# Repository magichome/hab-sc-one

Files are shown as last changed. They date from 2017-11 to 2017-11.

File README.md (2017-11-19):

## SCHab One
Definition: SCHab - _Shipping Container Habitat_

### Description
This is an effort to design a self-contained habitat based on a standard 40' HC Shipping Container.  It's more than just a drawing.  I plan to research, document, and design each subsystem that goes into building such a habitat: electrical, plumbing, hvac, etc.  Then I plan to build one.

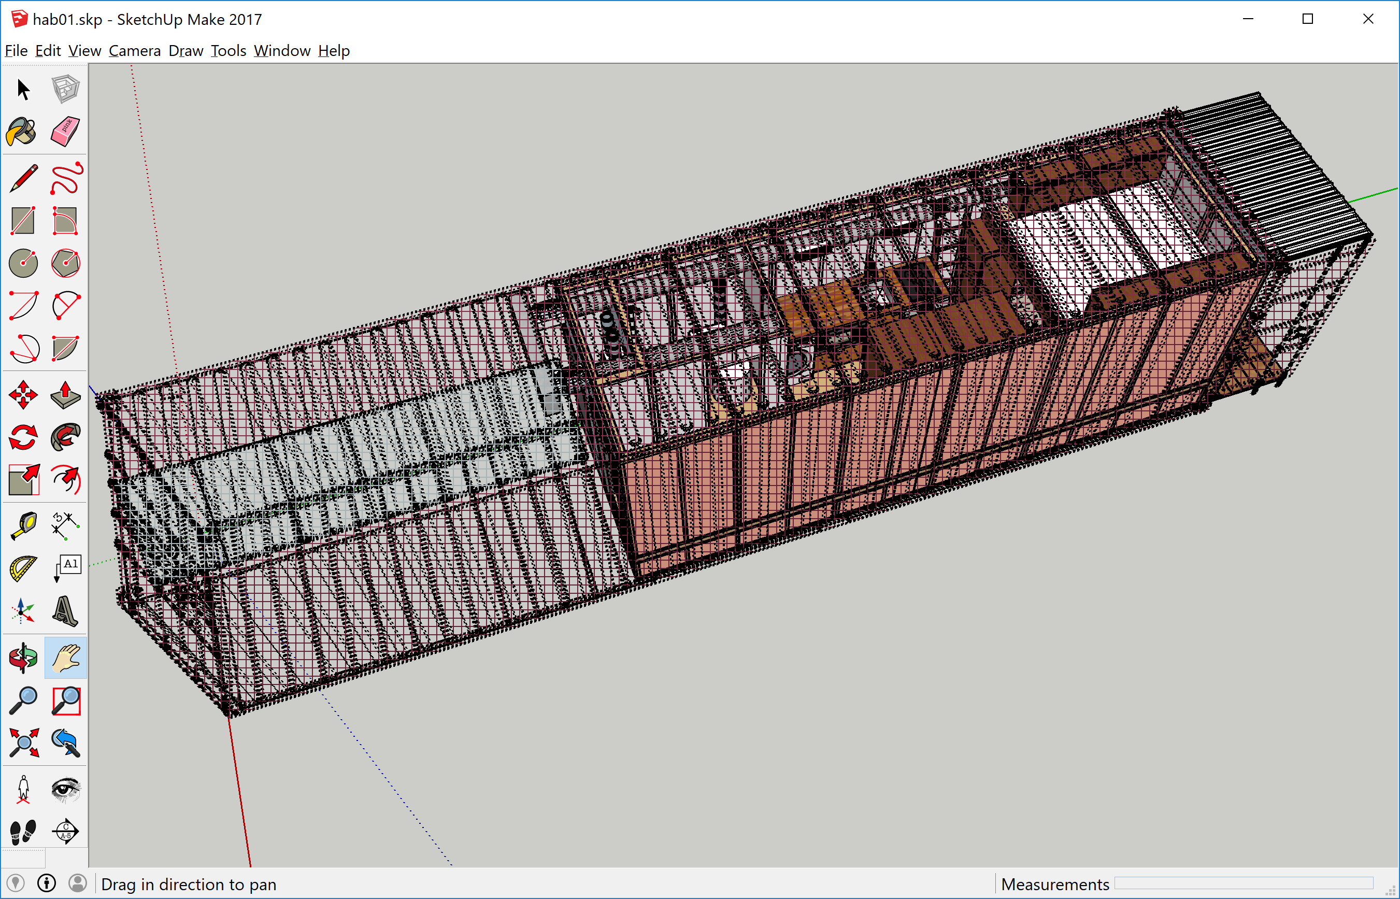
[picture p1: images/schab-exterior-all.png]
Exterior View


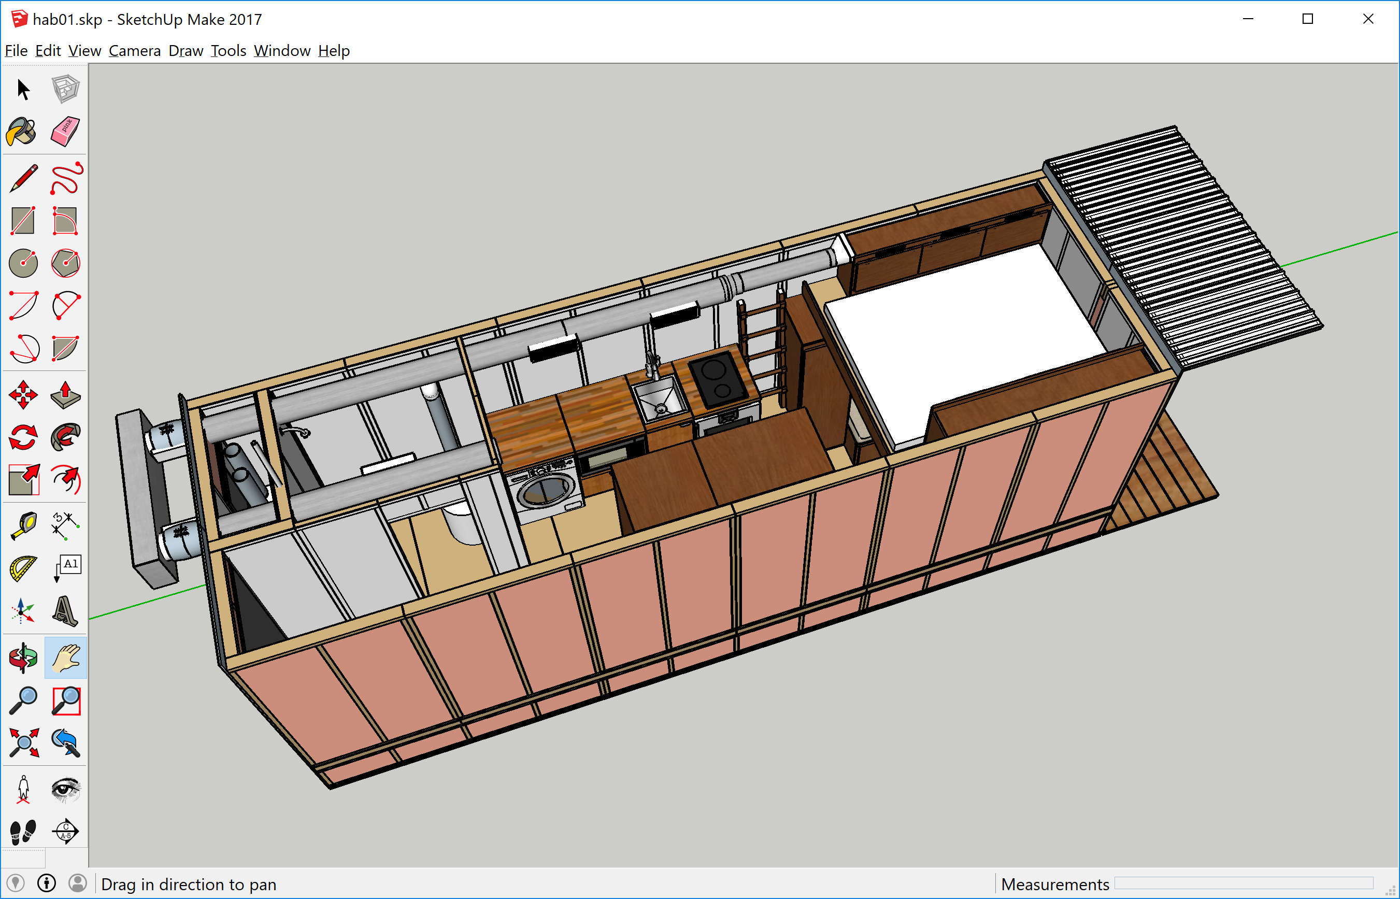
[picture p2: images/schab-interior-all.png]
Interior View


### Background
In order to explain why we're doing this, let me share a little background.  Currently we live in a small RV*.  We travel around the country as required by work or inclination.  While we've been doing this for about 4 years, I know we won't be doing it forever.  I can see a point when we'll want to spend time in a single location for part of the year.  Maybe at first a mixture of RV living and settled living.  Later probably more toward settled living.

**But why use a shipping container?**

A few reasons.  First, when we decided to live in an RV, mobility was the main requirement.  But we also wanted to downsize - minimal lifestyle, minimal impact, minimal cost.  A shipping container has more than enough room for us.  In fact it will be a step up from our current ride.

Second, we don't know where we'll buy land to set this up - we'll figure that out as we continue our current nomadic living.  We do have a place where we can start construction on the habitat and work on it for a few months out of the year.  So we can start building it now, purchase land later, and relocate it.

Third, even though we plan to buy land for SCHab, its unlikely we'll want keep it in one place indefinitely.  Maybe a location that appeals to us a few years from now won't work us 10 years from now.  The self contained shipping container habitat that we're planning will be relocatable. If we get tired of one place, we can have it moved to another.

**Why not a single-wide or 5th wheel trailer?**

Either of these could work but they are generally not self container.  They need water, sewer and electrical hookup.  The kind of land we're considering is generally off-grid and far from public utilities.  Electric could be brought in but that drives up the cost.  Adding a well and septic system also drives up the cost.  Minimal cost is one of our design goals.

Security is also a consideration.  Since we may only occupy our SCHab a few months out of the year, we want it to be as secure as possible while we're gone.  While nothing will keep out a determined bugler with the proper tools, a shipping container will be harder to break into than any trailer.  A shipping container will also stand up to harsh weather better.

And besides, this planning and construction is fun!

### Features
Since this is a work-in-progress the features are evolving.  Since we're use to living in our RV, some of these choices were informed by things that are working for us now.  Here's what I have so far:
* Completely contained in a 40' HC double-door shipping container.
* Single sleep area with queen size mattress
* Porch area for covered outdoor seating
* 7' x 15' garage area for a vehicle or outdoor toys
* Solar or wind electric with battery storage and AC inverter
* Single unit washer / dryer
* Marine refrigerator / freezer (12vdc)
* Oven / Stove / Microwave
* On-demand water heater (propane)
* Radiant heat
* Waterless toilet
* Storage tank for rainwater harvesting
* Provisions for a second story for those who need more space

### Getting Started
Drawing were made using [SketchUp](https://www.sketchup.com/).  The "free for non-commerical use" version, called SketchUp Make, can be downloaded at https://www.sketchup.com/download.  If you want to look at the drawings, you'll need to download and install SketchUp.

You'll want a local copy of this repository with all of the design files.  If you have GIT, you can clone the repository in the usual way.  If you have no idea what that means, you can download a zip archive by selecting the "Clone or Download" button above.

Some of the analysis is done using Microsoft Excel worksheets.  If you don't have Excel you can use the free office suite [Libre Office](https://www.libreoffice.org/).

### Project Resources

| Link | Purpose |
| --- | --- |
| [Research](Research/Research.md) | Information captured from research into various aspects of the project. |
| [Requirements](Requirements/Requirements.md) | Capture requirements for SCHab and its various subsystems. |
| [Design](SketchUp/Design.md) | 3D drawings |
| [Construction](Construction/Construction.md) | Information about construction considerations. |
| [Control](Control/Control.md) | Monitoring and control system. |
| [Trello Board](https://trello.com/b/0bdXyXfJ) | Here you can check on tasks I've identified and my status on those tasks. |

### Disclaimer

I am not an architect or engineer.  I didn't even stay at a Holiday Inn Express last night.  My background is science and IT.  While I'm aware of many building codes, I won't claim that any of what I have here is proper or up to code.  Frankly since this is "temporary housing", I'm not even sure what building codes apply.  Since my plan is to locate our SCHab in unincorporated areas, I'm not too concerned about it.  Obviously if you plan to build one yourself you'll want to understand the CC&R of the land you purchase and the building codes of the community.

Also, products we mention may link to Amazon.  As such, Amazon requires that we tell you the following:

"We are a participant in the Amazon Services LLC Associates Program, an affiliate advertising program designed to provide a means for us to earn fees by linking to Amazon.com and affiliated sites.”

--

\* You can read more about the RV on our blog (https://www.b190exp.com/) and follow us on [Instagram](https://www.instagram.com/b190exp/)

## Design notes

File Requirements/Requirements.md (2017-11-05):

## SCHab One : Requirements

Its generally a good idea to have in mind what you want, your requirements, before you go about designing and building it.  Here's what I have in mind for the requirements of SCHab One.

| General Requirements |
| ----- | ----- |
| No. | GEN01 |
| Title | SCHab shall be completely transportable in a single 40' HC Shipping Container. |
| Description | While some components of SCHab may be placed outside the container while in use, everything must be attached or contained within the container so it can be shipped as a single unit. |
| | |
| No. | GEN02 |
| Title | Other than service entries, SCHab shall not have penetrations in the shipping container skin. |
| Description | Entry will be at either end with the shipping container doors open.  Other than vents, water, sewer and electrical connections, there will be no other openings in the container (e.g. no doors or windows on the sides.) |
| | |
| No. | GEN03 |
| Title | SCHab shall require minimal site preparation. |
| Description | Other that the need to be level and room to open the doors, SChab shouldn't have any onerous site requirements. |
| | |
| No. | GEN04 |
| Title | SCHab shall provide suffcient sleeping space for 2 adults. |
| Description | In other words, a queen size bed. YMMV |

| Electrical Requirements |
| ----- | ----- |
| No. | ELEC01 |
| Title | Combined electrical generation and storage capacity shall meet 120% of expected average load over the course of habitation period. |
| Description | Some excess capacity is needed to support future growth.  At the same time it isn't necessary to provide capacity for those periods where the habitat is expected to be empty. |
| | |
| No. | ELEC02 |
| Title | Combined electrical generation and storage capacity shall meet 120% of the minimal sustaining load over the course of the non-habitation period. |
| Description | When we're not living in our SCHab, it will still have some electrical load requirements.  E.g. security and monitoring system, freeze protection, etc.
| | |

| Plumbing Requirements |
| ----- | ----- |
| No. | PLUM01 |
| Title | Water collection plus reserve supply shall meet 110% of the expected average usage during the habitation period. |
| Description | Compared to electric, water is a little easier to conserve so its requirement is a little lower. |
| | |
| No. | PLUM02 |
| Title | Black water and gray water shall be handled separately. |
| Description | While not all jurisdictions differentiate between black water and gray water, they can be handled differently.  For example, gray water can be recycled for irrigation.  I make sense to keep them separate. |

| Heating Requirements |
| ----- | ----- |
| No. | HEAT01 |
| Title | Heating generation capacity shall be sufficient to maintain a minimum of 65F during the coldest average conditions during the habitation period. |
| Description | This is complicated because it depends largely on the heat leakage of SCHab.  We'll take a stab at it. |
| | |
| No. | HEAT02 |
| Title | SCHab shall maintain HEAT01 for a period of 60 days without manual intervention. |
| Description | This deals with the size of the propane tanks.  I don't want to be having them refilled more frequently than this. |

| Ventilation Requirements |
| ----- | ----- |
| No. | VENT01 |
| Title | Ventilation shall be sufficient to keep indoor temperature within 5F of outside ambient temperature. |
| Description | I'm just pulling this one out of my rear.  I know that it is hard to keep a big, closed container cool with the sun beating down on it. Basically it needs enough ventilation to not become a sweat box on mild days. |

| Construction Requirements |
| ----- | ----- |
| | |

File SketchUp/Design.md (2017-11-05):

## SCHab One : Design

### Tools

Drawing were made using [SketchUp](https://www.sketchup.com/).  The "free for non-commerical use" version, called SketchUp Make, can be downloaded at https://www.sketchup.com/download.

### Schematics

These are found in the 'Schematics' directory.

### 3D Drawnings

The main SCHab 3d drawing is the file _hab01.skb_.  It is built up of components that can be found in the various SketchUp subdirectories.  These components can be opened and edited in SketupUp individually.  Note, however, that changes are not automatically reflected in the overall hab01.skb drawing.  You would need to select the component in hab01.skb and "reload" it from the edited component file.

I found the [shipping container model](https://3dwarehouse.sketchup.com/model/ub2c368e2-d333-4a4c-81ff-acfce363f53e/Open-Top-40ft-High-Cube-Container-w2-Doors) in the SketchUp 3D Warehouse.  It was created by OrganicZero so they deserve credit for it.

### HVAC

I don't plan for air conditioning in the current design.  If you need A/C, it may be possible to add an evaporator coil to the ventilation input duct and add a return air duct somewhere.  One could certainly add a split unit.  Instead I have a couple high volume blowers that will circulate outside air.  That along with  natural ventilation through screen doors should help keep the temperature down.

For heating, the space is small enough it could be heated with a pellet stove.  So in some sense radiant heat (my choice) is overkill.  Having lived with radiant heat in the past, I like it.  So here it is.

On a personal note, before I started living in an RV I had a fairly narrow comfort range for home temperature.  About 71F in the winter and 69F in the summer.  Now I find that I can function just fine with temperatures anywhere between 60F and 90F inside.  You just get use to it.  So I'm not inclined to design an HVAC system according to my old sensibilities.  YMMV.

#### Radiant Heat

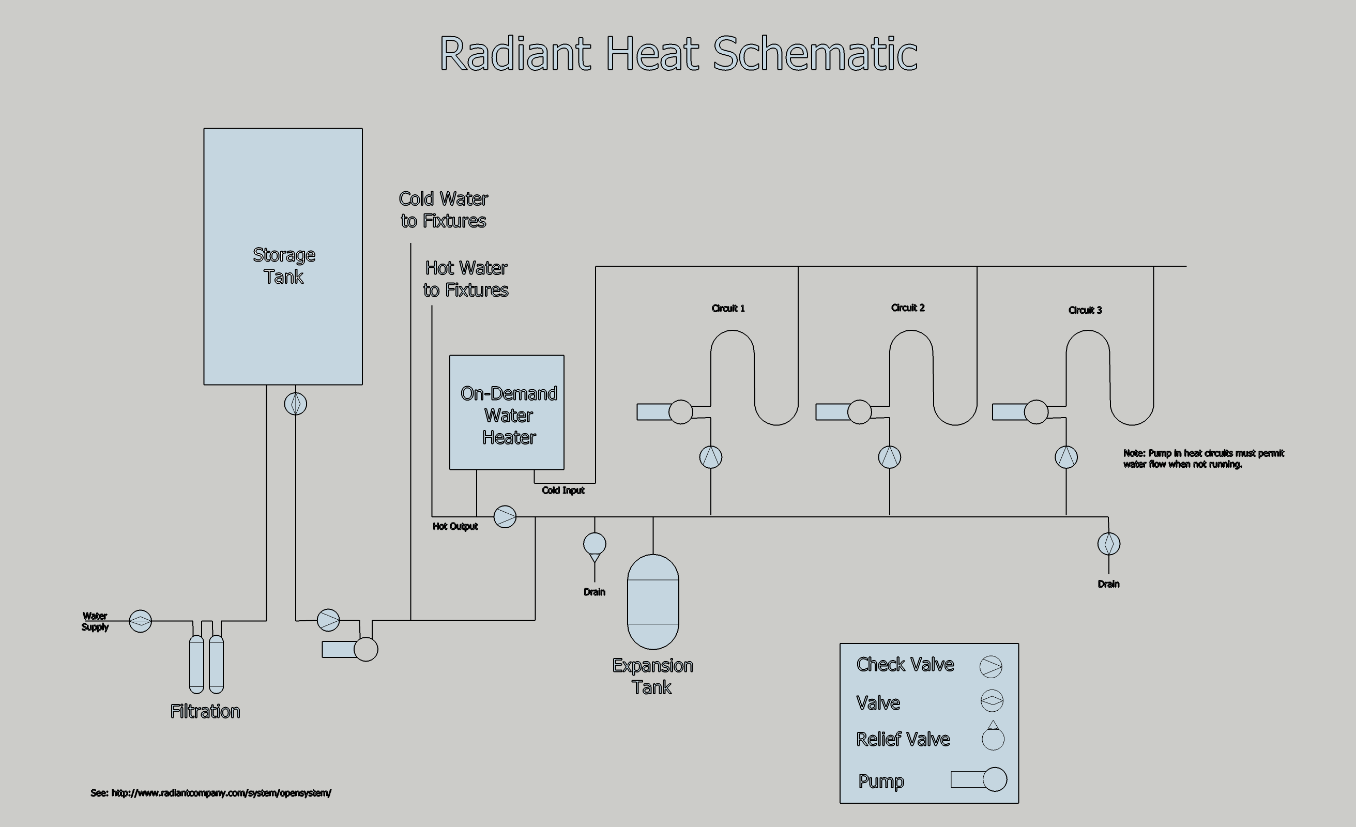
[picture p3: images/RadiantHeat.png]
Schematic


This is an open loop system.  That means the water that heats the floor is the same water that comes out of the faucet.  With a system like this you need to make sure the water is circulated throughout the system even when heat isn't used.  You don't want the water to stagnate.  That's why you see the (strange) connection between the cold water input and the radiant heat circuit.  Basically the on-demand water heater's cold water input is through the radiant heat system.  The folks at  [www.radiantcompany.com](http://www.radiantcompany.com/system/opensystem/) explains how this works so I won't repeat it here.

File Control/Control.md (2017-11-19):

## SCHab One : Control

Given my background in IT, you shouldn't be surprised that I intend to trick out SCHab with some impressive monitoring and control gizmos.

### Monitoring
* Indoor air temperature
* Outdoor air temperature
* Battery voltage
* Solar / Wind current input
* Usage current
* Water temperature input to radiant heat circuits
* Water temperature return from each circuit
* Water pressure
* Water storage tank level
* Propane tank levels

### Control
* Radiant heat pumps
* Ventilation fan speed
* Lights

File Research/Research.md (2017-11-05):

## SCHab One : Research

Several subsystems of SCHab are complex topics in their own right.  Here I look for resources that have already done some of the heavy lifting.  Research topics include:

* [Rainwater Harvesting](#rainwaterharvesting)
* [Gray Water Disposal](#greywaterdisposal)
* [Gray Water Recycling](#greywaterrecycling)
* [Solar Power Generation](#solarpower)
* [Wind Power Generation](#windpower)
* [Radiant Heat](#radiantheat)
* [Purchasing Shipping Containers](#scpurchase)
* [Transporting Shipping Containers](#sctransport)

### Rainwater Harvesting

First, I don't want to have a well drilled.  Depending on location this can be quite expensive.  A well also increases the electrical requirements.  I know that statistics show the average person takes some 25 - 50gal per day.  I also know, living in the RV, that I can made do with much less.  I don't have big water wasters like lawn watering, a flush toilet, or long showers.  So rainwater harvesting seems like a viable solution.

From my research so far, harvesting off a shipping container is problematic.  First, its flat.  The rainwater will run off all over the place.  Even if we could catch it, 40' x 8' isn't much of a collection area.  There are few places in the country where 320 sq ft of collection area will give you enough water.

There is also the question of storage.  I have designed in a 275 gal bladder tank in the crawl space.  That will help get through some dry months but it isn't a huge amount.

Generally rainwater harvesting is broken down into the following categories:

* Collection
* Storage
* Filtration
* Treatment

Collection is mainly focused on the surface area required to collect the amount of water you'll need given the average rainfall in your area of choice.  You'll get roughly 0.62 gal per sq ft per inch of rain.  My [RainHarvestingProjections.xlsx](Research\RainwaterHarvesting\RainHarvestingProjections.xlsx) spreadsheet shows some calculations for a couple locations.

Storage is needed to carry you through times when there is no rain.  So while collection area can be based on average annual rainfall, you'll need to look at monthly rainfall averages to determine storage requirements.  Let's say, for example, that a location gets 50in of rain per year.  You can design the collector to capture enough of that 50in to satisfy your needs.  But say that those 50in only come over a couple months in the spring.  Then you'll need a large storage capacity to keep you in water for the other 10 months.  On the other hand, if those 50in are spread evenly over the year, you'll need less storage.  Maybe only enough to carry you for a week or two.  The above spreadsheet takes that into consideration.

Filtration removes particulates from the water.  It is a multi-stage process that starts with screens at the gutters, a 'first flush' mechanism, particulates settling out in the storage tank, then two or three filters.

Treatment kills microorganisms that may be in the water.  I'm leaning toward a UV system since that seems easiest to install and maintain.

Most rainwater harvesting designs do things in this order:

collection -> storage -> filtration -> treatment

I've decided though that I don't want unfiltered or untreated water in my storage tank.  I don't want particulates settling out in my storage tank because I don't want to worry about periodically cleaning it out.  Instead I'm thinking of the following:

collection -> catch basin -> filtration -> treatment -> storage

The catch basin would be outside and sized to collect the water from an average rainfall.  A pump would move the water from there, through the filtration/treatment system and into storage. I haven't research this much so I don't have answers to these questions:

* How fast can I pump water through the filtration/treatment system?  If we have a deluge, can I pump it fast enough to keep the catch basin from overflowing?
* How do I keep all of this from freezing in the winter?
* How do I harvest snowfall if that becomes a consideration?

### Gray Water Disposal

Let's speak frankly.  Gray water is the waste water you generate than doesn't have poop.  Black water is waste water that does have poop.  Since I'm planning to use a waterless toilet, all of the waste water for SCHab will be gray water.  

Note: Some jurisdictions treat gray water the same as black water.  If you're in one of those areas, you'll need a septic system anyway.

You could just run the gray water onto the ground.  In the interest of full disclosure, the SCHab gray water will have pee.  (Urine is quite sterile but not everyone knows that.)  Having urine smell around your SCHab is probably not a good idea.  Right now I'm thinking of a [french drain](https://en.wikipedia.org/wiki/French_drain) located some distance from the SCHab.  That may change if it looks like gray water recycling (e.g. garden irrigation) would be a good idea for me.

Note: You don't want to store gray water unless you plan to later dispose of it as black water.  The microbes in gray water will eventually turn it septic.

### Gray Water Recycling

If you're in a really arid region you may want to keep every drop of water you can.  Is it possible to pump your gray water back into your rainwater harvesting system and not make everyone sick?  I'm sure it's possible (they recycle water on the ISS) but it may not be practical.  

Irrigating a garden is an easy recycling plan. Just plumb the gray water drain pipe to irrigation pipes.  Maybe a diverter valve to a french drain to control the amount of water to the garden.

### Solar Power Generation

This one is easy for me.  We use solar power in our RV.  Renogy solar panels, Vmaxtank AGM batteries, and MPPT charge controller are my choice.  I am going to try Renogy's polycrystalline panels this time even though I have monocrystalline panels on the RV.  Polys are less expensive but less efficient than monos.  Poly panels need to be larger to get the same power output.  On my RV, with limited roof space, smaller panels are a good thing.  On SCHab it's less important so I'd rather have the lower cost.  The main question here is how many panels and batteries do I need for the electrical load.

### Wind Power Generation

I've not used wind power but considering it due to my acute familiarity with the limitations of solar.  If you're in an area with long periods of cloudy skies you may need to dramatically increase the number of solar panels and batteries necessary to keep the lights on.  That isn't cheap.  Depending on location, it may make sense to supplement solar power generation with wind.  More research to come.

### Radiant Heat

Coming...

### Purchasing Shipping Containers

SCHab will use a 40' HC DD shipping container. 40' because that's its length.  HC mean 'high cube' with means 9'6" tall instead of the usual 8'6" tall.  DD mean 'double-door', a door at both ends.  I won't go into all of the ins and outs of shipping containers, e.g. new vs one-trip vs used.  A [simple Internet search](https://duckduckgo.com/?q=shipping+or+conex+containers) will take care of that (search for 'conex' as well as 'shipping container').  I do believe that the double-door variant is harder to find.  Also, you'll want to buy local to cut down on transportation costs.  I'll do more here when I get closer to buying a container.

### Transporting Shipping Containers

Coming...

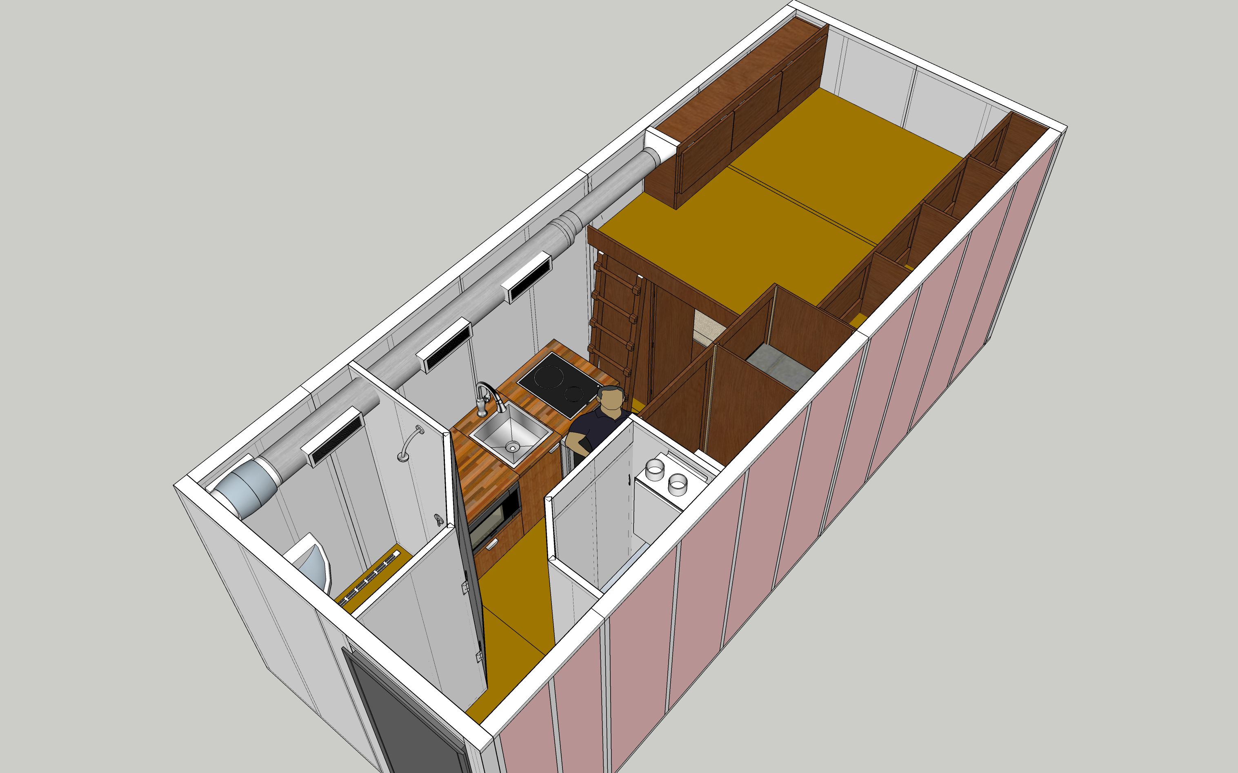
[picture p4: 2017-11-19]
images/hab-20-02.interior-allpng.png

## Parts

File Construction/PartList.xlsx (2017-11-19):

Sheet: Summary
Cost Summary
Appliances | $4705.00
Electrical | $3240.00
Solar | $1188.00
Wind | $0.00
Plumbing | $2580.00
HVAC | $360.00
Construction | $6343.11
Total | $18416.11

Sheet: Appliances
Item | Make | Model | Watts | Price Est | Supplier | Notes
Microwave |  |  |  |  |  | 22"
Range Hood |  |  |  |  |  | 22"
Oven / Stove |  |  |  |  |  | 22"
Washer / Dryer | LG | WM3488HW (http://www.lg.com/us/washer-dryer-combos/lg-WM3488HW-front-load-washer) | 1200 | $1415.00 | amazon.com (https://www.amazon.com/gp/product/B01H7HYF86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)
Waterless Toilet | Separett | Villa 9210 (https://separett-usa.com/index.php/waterless-urine-diverting-toilet.html) | 2.5 | $1190.00 | separett-usa-orders.com (https://www.separett-usa-orders.com/collections/waterless-toilets/products/villa-9210-dc)
LED TV | Vizio | D55-D2 | 40 | $580.00 | amazon.com (https://www.amazon.com/VIZIO-D55-D2-Class-Array-Smart/dp/B019PZD68I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) | Just an example to get idea of power requirements.
Refrigerator | Vitrifrigo | DP2600IBD4-F (http://www.vitrifrigo.com/us/us/dp2600ibd4-f-internal-cooling-unit) | 65 | $1520.00 | marinewarehouse.com (http://www.marinewarehouse.net/Vitrifrigo.html)
Total |  |  |  | $4705.00

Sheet: Electrical
Item | Make | Model | Watts | Qty | Price Est | Total | Supplier | Notes
Storage Battery | Vmaxtanks | SLR125 |  | 8 | $280.00 | $2240.00 | amazon.com (https://www.amazon.com/gp/product/B00ACNO2AO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)
Battery Monitor | Victron Energy |  |  | 1
Inverter | Sun Gold Power | 3000W |  | 1 | $640.00 | $640.00 | amazon.com (https://www.amazon.com/SUNGOLDPOWER-Inverter-Frequency-Converter-Priority/dp/B00QSWCZC0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)
DC Breaker Panel | Blue Sea Systems | Traditional 8-position |  | 1 | $190.00 | $190.00 | amazon.com (https://www.amazon.com/Traditional-Metal-DC-Panel-Positions/dp/B000K2MAYW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)
AC Breaker Panel | Blue Sea Systems | Traditional 6-position |  | 1 | $170.00 | $170.00 | amazon.com (https://www.amazon.com/Traditional-Metal-Panel-Main-Positions/dp/B0000AXNUY?s=sporting-goods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)
Lighting
Accent Lighting |  |  |  |  |  |  |  | Strip LED
Kitchen Ceiling Light
Kitchen Task Light
Bathroom Ceiling Light
Living Area Lighting
Bed Area Lighting
Utility Room Lighting
Crawl Space Lighting
Exterior Lighting
Total |  |  |  |  |  | $3240.00

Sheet: Solar
Item | Make | Model | Watts | Qty | Price Est | Total | Supplier
Solar Panel | Renogy | 100W Polycrystalline |  | 6 | $118.00 | $708.00 | amazon.com (https://www.amazon.com/Renogy-Polycrystalline-Photovoltaic-Solar-Module/dp/B00DCCOSV0?dpID=51PP4atr35L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)
Charge Controller | Renogy | 60A MPPT |  | 1 | $480.00 | $480.00 | amazon.com (https://www.amazon.com/dp/B01DCU4M0S?linkId=4fe2e1bcd93676475c9587820d5addf8)
Total |  |  |  |  |  | $1188.00

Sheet: Wind
Item | Description | Qty | Price Est | Total | Supplier | Notes
Total |  |  |  | $0.00

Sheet: Plumbing
Item | Make | Model | Watts | Qty | Price Est | Total | Supplier | Notes
Water Heater | Takagi | T-H3M (http://www.takagi.com/products/tankless-water-heaters/t-h3m-dv-p) | 54 | 1 | $790.00 | $790.00 | tanklessonline.com (http://www.tanklessonline.com/takagi-high-efficiency-tankless-water-heater-t-h3m-dv-p-indoor-propane.html) | On-demand. For both hot water and radiant heat.
Water Pump | Flojet | 2840-100 | 120 | 1 | $600.00 | $600.00 | pumpvendor.com
Holding Tank | Fol-Da-Tank | PW-275 (http://www.fol-da-tank.com/page/Collapsible%20Tanks%20for%20Water%20Shuttle%20and%20Storage.aspx?nt=138) | n/a | 1 | $760.00 | $760.00 | amazon.com (https://www.amazon.com/Fol-Tank-PW-275-SB-Pillow-Portable/dp/B01N6XZ4LE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) | Flexible tank so it can be removed from crawl space for cleaning or repair.
Bath Sink |  |  |  |  |  | $0.00
Bath Faucet |  |  |  |  |  | $0.00
Shower System | Perfetto | SP0057 | n/a | 1 | $230.00 | $230.00 | amazon.com (https://www.amazon.com/dp/B01HSFLYD6?linkId=c85b8255f12e06013fa0d67b8d8dbdac)
Shower Drain | DreamDrain | 48" Stainless | n/a | 1 | $100.00 | $100.00 | amazon.com (https://www.amazon.com/DreamDrain-Brushed-Stainless-Linear-Squares/dp/B013VR8I3Y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)
Kitchen Sink | Perfetto | 15" x 20" x 9" | n/a | 1 | $100.00 | $100.00 | amazon.com (https://www.amazon.com/Perfetto-Kitchen-Bath-Stainless-Undermount/dp/B073DF9QFR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)
Total |  |  |  |  |  | $2580.00

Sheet: HVAC
Item | Make | Model | Watts | Qty | Price Est | Total | Supplier | Notes
Ventillation Blower | Vortex | S-800 (http://vortexpowerfans.com/s800) | 232 | 2 | $180.00 | $360.00 | amazon.com (https://www.amazon.com/Vortex-711-CFM-S-Line-S-800/dp/B00EISCUQM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)
Circulation Pump |  |  |  | 3 |  |  |  | For radiant heat.
Pellet Stove |  |  |  |  |  |  |  | Optional, for cold climates.
Heat Exchanger |  |  |  |  |  |  |  | Could fit into ventilation duct. Optional, for cold climates.
Bath Exhaust
Inlet duct
Duct 8"
Duct 6"
Reducer 8" - 6"
Adapter 6" - rect
Duct Side Vent |  |  |  | 3
Duct End Vent
Cabinet Vent |  |  |  | 3
Total |  |  |  |  |  | $360.00

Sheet: Construction
Item | Description | Qty | Price Est | Total | Supplier | Notes
Shipping Container | 40ft HC DD | 1 | $4000.00 | $4000.00 |  | Estimate. Double-door harder to find.
Delivery Cost
Dimensional Lumber | 2" x 4" x 8' | 94 | $3.29 | $309.26
Dimensional Lumber | 2" x 2" x 8' | 15 | $1.78 | $26.70
OSB | 7/16" x 4' x 8' | 13 | $18.65 | $242.45
Insulation - Bat | 24" x 4" x 48" | 88 | $745.00 (https://www.homedepot.com/p/Owens-Corning-R30-Insulation-Unfaced-Batts-24-in-x-48-in-8-Bags-BU70/202756617) | $745.00 |  | Bundle price for 80.
Insulation - Panel | 1.5" x 4' x 8' | 6 | $24.00 (https://www.homedepot.com/p/Owens-Corning-Foamular-150-1-1-2-in-x-4-ft-x-8-ft-R-7-5-Scored-Squared-Edge-Insulation-Sheathing-88WD/202085958) | $144.00
Plastic Panel | 1/16" x 4' x 8' | 15 | $19.98 (https://www.homedepot.com/p/1-16-in-x-4-ft-x-8-ft-Plastic-Panel-63003/202090190) | $299.70
Gypsum Firebreak | 5/8" x 4' x 10'
Entry Door |  | 2 | $288.00 (https://www.homedepot.com/p/L-I-F-Industries-36-in-x-80-in-Gray-Right-Hand-Fire-Steel-Prehung-Commercial-Door-3RK/202080890) | $576.00
Utility Door
Bathroom Door
Total |  |  |  | $6343.11

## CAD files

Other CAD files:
SketchUp/Bath/LinearDrain.skp
SketchUp/Bath/shower_base_kohler9396.skp
SketchUp/Bath/sink-bathroom-2011-71-sk.skp
SketchUp/Bath/sink-corner.skp
SketchUp/Bath/toilet-waterless-separett.skp
SketchUp/Cabinets/CABINET+HANDLE+02.skp
SketchUp/Cabinets/Finial+Hinge.skp
SketchUp/Cabinets/cabinet-livingroom.skp
SketchUp/Cabinets/cabinet-wardrobe.skp
SketchUp/Cabinets/louvered+vents.skp
SketchUp/Cabinets/upper-vent-22in.skp
SketchUp/Components/32_+Shower+Stall.skp
SketchUp/Components/Base Panel.skp
SketchUp/Components/CrawlSpace-End.skp
SketchUp/Components/CrawlSpace-Side.skp
SketchUp/Components/Door-Steel-24in.skp
SketchUp/Components/Door-Steel-30in.skp
SketchUp/Components/DrawerSlides.skp
SketchUp/Components/Hinge+-+4.skp
SketchUp/Components/Insulation-CrawlSpace-Side.skp
SketchUp/Components/Insulation-FloorCeiling.skp
SketchUp/Components/Ladder-Bed-5ft.skp
SketchUp/Components/Lumber2x2.skp
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

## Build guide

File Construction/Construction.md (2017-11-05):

## SCHab One : Construction

### Tools

General carpentry tools should be sufficient for most of the construction.  Table saw, circular saw, nail gun, glue gun, etc.  Since the shipping container is steel, we'll also need some metal working tools.  Specifically we'll need to cut openings for vents on the roof and service entry on the side.  I plan to fabricate an elevated steel box for the vents and a recessed steel box for the service entry.  So you'll need an angle grinder with cutting wheels and a welder to weld the boxes to the shipping container.

### Construction Considerations

First, since SCHab is designed to be relocatable, we'll have to consider how transporting it can impact the structure.  Sliding on and off trailers, as well as bouncing along roads, is not something encountered by typical residential construction.  

Second, the steel of the shipping container will expand and contract as temperature varies much more than the wood framing inside.

Finally, shipping containers are not as strong as you might think.  Yes they are designed so they can be stacked 8 high but that's only because the corners and ends are strong.  The rest of the structure is just enough to keep the weather out.  If you've ever seen a front loader lift one at the corner (you can find examples on youtube.com), the container will twist and flex.

With these considerations in mind, I've made the following construction decisions:

* Only the floor of the framed interior is attached to the shipping container.  The walls and ceiling are free standing.

This way the shipping container can expand, contract and flex to a degree without impacting the interior framing.

* Interior walls and ceiling are sheathed with 1/16" plastic panels instead of sheetrock.

Sheetrock is heavy and I suspect after bouncing down the road it would crack at the attachment screws and the seams.  Also I've done enough sheetrock work in my life that I don't want to do any more.  Added bonus, no painting required.

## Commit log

2017-11-02 initial checkin
    [32_+Shower+Stall.skp, Base Panel.skp, Base_1door_1drawer21Wx34.skp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]
2017-11-03 various updates
    [Electrical.xlsx, HVAC.xlsx, PartList.xlsx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]
2017-11-05 mostly docs updates
    [PartList.xlsx, RadiantHeat.skp, components-2017-11-04.csv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]
2017-11-19 added 20ft model
    [M-indokeen+ISO20.skp, PartList.xlsx, cabinet-livingroom.skp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]
2017-11-20 added drains for 20ft hab
    [12inTrap.skp, AAV.skp, CABINET+HANDLE+02.skp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]
2017-11-21 added plumbing for hot/cold/heat in utility area
    [checkvalve-pvc-1_2in.skp, pump-circulator-PUA0125GEN.skp, valve-pvc-uniblock-1_2in.skp]
